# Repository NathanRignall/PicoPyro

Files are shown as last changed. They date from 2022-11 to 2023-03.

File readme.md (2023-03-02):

# Pico Pyro v1.0.1
DMX controlled dual pyrotechnic channels.

## Hardware Overview
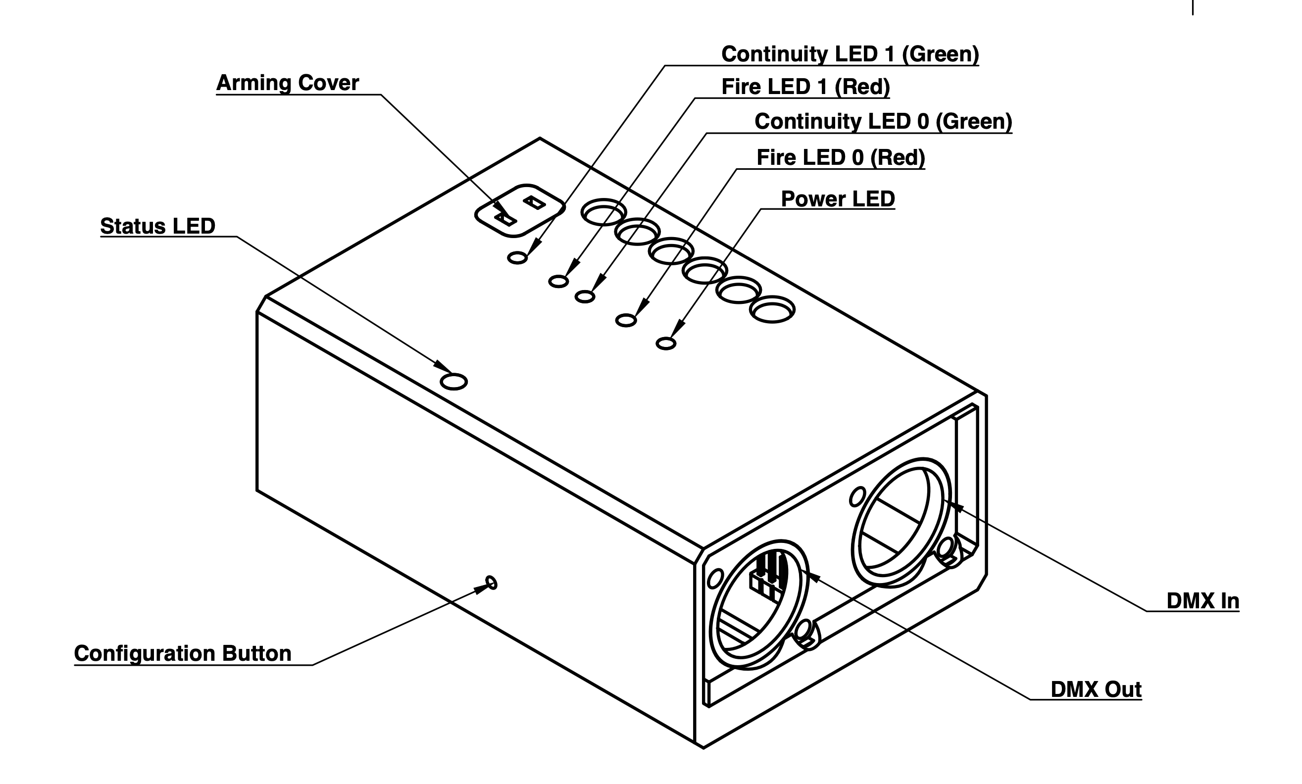
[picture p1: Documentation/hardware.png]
Hardware Diagram

 - Status LED - (WHITE, GREEN, RED, BLUE, PURPLE)
 - Continuity LED - (GREEN)
 - Fire LED - (RED)
 - Configuration Button
 - Arming Cover
 - DMX In/Out

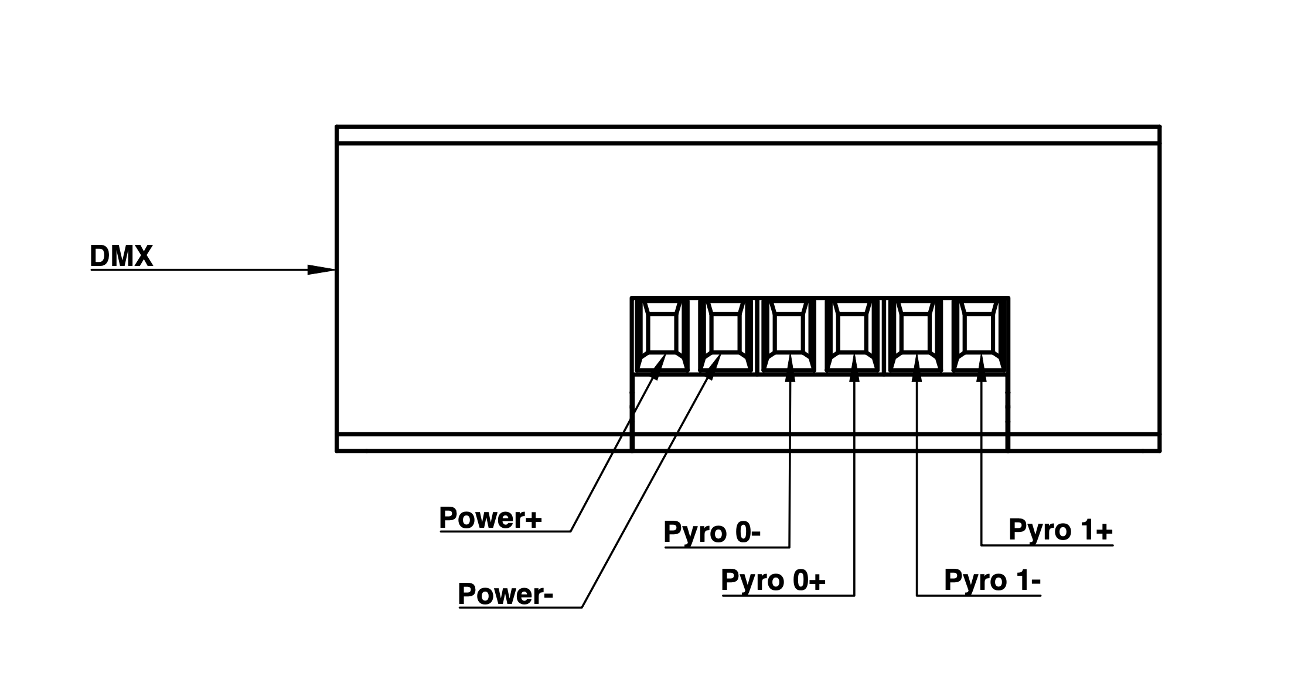
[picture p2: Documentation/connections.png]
Connections Diagram

 - Power+ (3v-50v)
 - Power-
 - Pyro 0/1-
 - Pyro 0/1+

## Modes
The Pico Pyro can be in one of three modes, these are indicated by the status LED.

By default the system enters **active** mode when turned on.

To enter **setup** mode the configuration button must be pressed while being turned on. Setup mode cannot be entered after booting.

If the system detects an invalid configuration during boot the system will enter **failed** mode. To resolved the system must be turned off and back on into setup mode.

### Active
 - Status LED is solid **GREEN** when DMX is detected, **RED** when no DMX signal is detected.
 - Continuity LEDs are **GREEN** when the voltage threshold is met across the pyrotechnic channels. These are used to show if there is a good connection across the hardware connected.
 - Fire LEDs are **RED** when the specified pyrotechnic channel is fired. This occurs when the DMX authorization and fire values are met for that channel.

### Setup
 - Status LED **BLUE**.
 - Continuity LEDs are **GREEN** when the voltage threshold is met across the pyrotechnic channels. These are used to show if there is a good connection across the hardware connected.
 - Fire LEDs and hence pyrotechnic channels off and ***cannot activate***.

### Failed
 - Status LED **PURPLE**.
 - Continuity LEDs off and cannot activate.
 - Fire LEDs and hence pyrotechnic channels off and ***cannot activate***.

## DMX Table

| Channel | Description |
| --- | --- |
| 1 | Pyrotechnic Channel 0 Authorization |
| 2 | Pyrotechnic Channel 1 Authorization |
| 3 | Pyrotechnic Channel 0 Fire |
| 4 | Pyrotechnic Channel 1 Fire |

The DMX values to activate the different channels are specified in the configuration tool.

## Setup
Once entering setup mode the system can be configured using the built-in website. This is accessed by connecting to the WiFi network that is broadcast and navigating to the IP address in the chosen browser.

**SSID** - PicoPyro  
**Password** - itsathing  
**URL** - http://10.66.0.1

The user should be presented with the following...
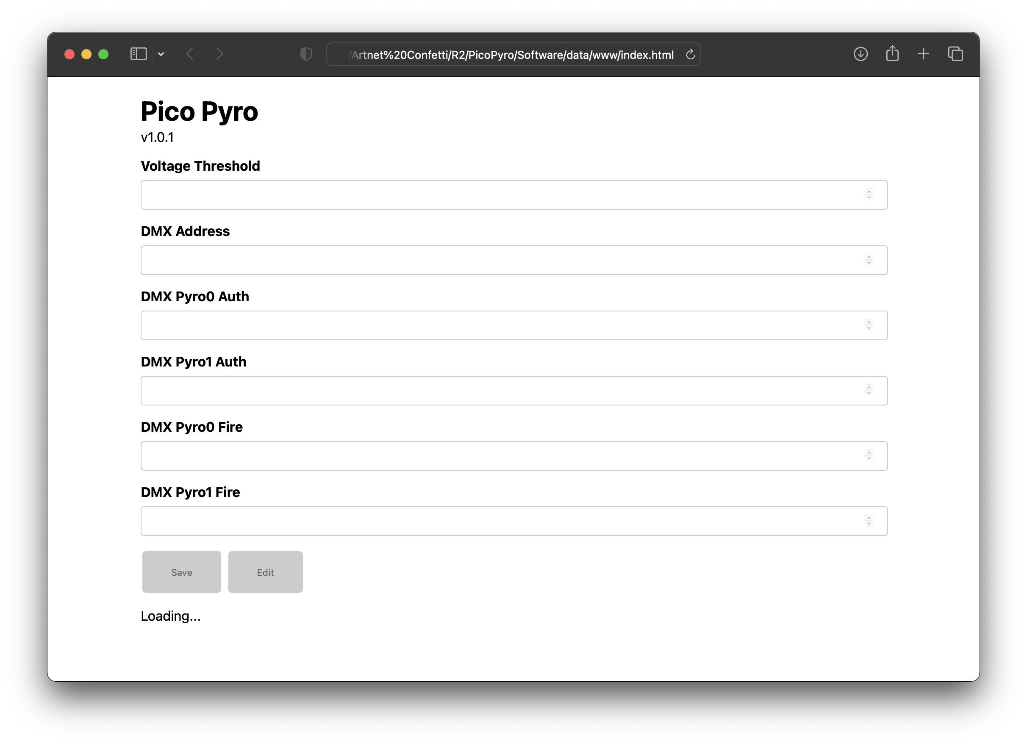
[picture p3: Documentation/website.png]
Website


 - Voltage threshold - (0-1023) - Value used to activate the continuity LEDs. This value is dependant on the supplied voltage. When supplied with around 12v an advised threshold value is 100.
 - DMX Address - (1-251) - Base address for all DMX channels.
 - DMX Pyro0 Auth - (0-255) - Value required to activate channel
 - DMX Pyro1 Auth - (0-255) - Value required to activate channel
 - DMX Pyro0 Fire - (0-255) - Value required to activate channel
 - DMX Pyro1 Fire - (0-255) - Value required to activate channel

## Usage Tips
Ensure all connections are attached.

Arming cover can be removed for rehearsals to test the behaviour of the system without activating pyrotechnic channels.  
When the arming cover is removed the channels are electrically disconnected and cannot fire. The continuity LEDs will temporarily stop working. Fire LEDs will work as expected but won't fire the pyrotechnic channels.  
The recommended method of removing the arming cover is by placing a cable tie through the loop and pulling backwards.

Do not set the activation value to 255, this will increase the chance of accidental activation.  
Instead use a selection of unique, different values.

The easiest way to integrate this system into lighting software is by patching 4 dimmer channels.

## Electronics
Voltage dividers are used for the continuity detection.  
Low voltage dropout is in the voltage regulator.

## Troubleshooting
 - The status LED should be constant **GREEN** when in normal operation.
   - Flickering to **RED** DMX connection is unstable
   - Flickering off supplied voltage is too low (especially during firing)
 - When not activating as expected this could be because the Grand Master is lowering the values slightly.
   - To combat this happening set the 'cue' to ignore the Grand Master

## Legal
We accept no responsibility for the consequences of activating a pyrotechnic.

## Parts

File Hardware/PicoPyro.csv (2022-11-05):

Source: | /Users/nathanrignall/Documents/Development/Projects/Artnet Confetti/R2/PicoPyro/Hardware/PicoPyro.kicad_sch
Date: | Friday, 04 November 2022 at 15:47:25
Tool: | Eeschema (6.0.8-1)-1
Generator: | /Applications/KiCad/KiCad.app/Contents/SharedSupport/plugins/bom_csv_grouped_by_value.py
Component Count: | 46
Individual Components:
Item | Qty | Reference(s) | Value | LibPart | Footprint | Datasheet | Description | Height | MANUFACTURER | MAXIMUM_PACKAGE_HEIGHT | Manufacturer_Name | Manufacturer_Part_Number | Mouser Part Number | Mouser Price/Stock | PARTREV | PN | SNAPEDA_PN | STANDARD
 |  | C101 | 100n | Device:C | Capacitor_SMD:C_0402_1005Metric | ~ |  |  |  |  |  |  |  |  |  | LMK105B7104KVHF
 |  | C102 | 100n | Device:C | Capacitor_SMD:C_0402_1005Metric | ~ |  |  |  |  |  |  |  |  |  | LMK105B7104KVHF
 |  | C301 | 100n | Device:C | Capacitor_SMD:C_0402_1005Metric | ~ |  |  |  |  |  |  |  |  |  | LMK105B7104KVHF
 |  | C501 | 10u | Device:C | Capacitor_SMD:C_0805_2012Metric_Pad1.18x1.45mm_HandSolder | ~
 |  | C502 | 10u | Device:C | Capacitor_SMD:C_0805_2012Metric_Pad1.18x1.45mm_HandSolder | ~
 |  | D201 | LED | Device:LED | LED_SMD:LED_0603_1608Metric | ~
 |  | D211 | LED | Device:LED | LED_SMD:LED_0603_1608Metric | ~
 |  | D301 | WS2812B | LED:WS2812B | LED_SMD:LED_WS2812B_PLCC4_5.0x5.0mm_P3.2mm | https://cdn-shop.adafruit.com/datasheets/WS2812B.pdf
 |  | D401 | LED | Device:LED | LED_SMD:LED_0603_1608Metric | ~
 |  | D411 | LED | Device:LED | LED_SMD:LED_0603_1608Metric | ~
 |  | D601 | LED | Device:LED | LED_SMD:LED_0603_1608Metric | ~
 |  | F201 | 0679H9100-05 | 0679H9100-05:0679H9100-05 | FUSC6125X279N | https://www.belfuse.com/resources/datasheets/circuitprotection/ds-cp-0679h-series.pdf | Surface Mount Fuses 10A 350 VAC 72 VCD | 2.79 |  |  | Stewart Connector | 0679H9100-05 | 530-0679H9100-05 | https://www.mouser.co.uk/ProductDetail/Bel-Fuse/0679H9100-05?qs=acBVhj9v9XU5kfUTxwyepA%3D%3D
 |  | F211 | 0679H9100-05 | 0679H9100-05:0679H9100-05 | FUSC6125X279N | https://www.belfuse.com/resources/datasheets/circuitprotection/ds-cp-0679h-series.pdf | Surface Mount Fuses 10A 350 VAC 72 VCD | 2.79 |  |  | Stewart Connector | 0679H9100-05 | 530-0679H9100-05 | https://www.mouser.co.uk/ProductDetail/Bel-Fuse/0679H9100-05?qs=acBVhj9v9XU5kfUTxwyepA%3D%3D
 |  | J001 | Conn_01x06 | Connector_Generic:Conn_01x06 | Connector_PinSocket_2.54mm:PinSocket_1x06_P2.54mm_Vertical | ~
 |  | J101 | XLR3 | Connector:XLR3 | Connector_Audio:Jack_XLR_Neutrik_NC3FAAH_Horizontal | ~
 |  | J102 | XLR3 | Connector:XLR3 | Connector_Audio:Jack_XLR_Neutrik_NC3MAAH_Horizontal | ~
 |  | J103 | Conn_01x03 | Connector_Generic:Conn_01x03 | Connector_PinHeader_2.54mm:PinHeader_1x03_P2.54mm_Vertical | ~
 |  | J201 | TB005-762-02BE | TB005-762-02BE:TB005-762-02BE | TB00576202BE | https://componentsearchengine.com/Datasheets/1/TB005-762-02BE.pdf | Fixed Terminal Blocks screw type, 7.62 , horizontal, 2 poles, CUI Blue, slotted screw, PCB mount | 21.7 |  |  | CUI Inc. | TB005-762-02BE | 490-TB005-762-02BE | https://www.mouser.co.uk/ProductDetail/CUI-Devices/TB005-762-02BE?qs=vLWxofP3U2zXv1H2wuShow%3D%3D
 |  | J202 | TB005-762-02BE | TB005-762-02BE:TB005-762-02BE | TB00576202BE | https://componentsearchengine.com/Datasheets/1/TB005-762-02BE.pdf | Fixed Terminal Blocks screw type, 7.62 , horizontal, 2 poles, CUI Blue, slotted screw, PCB mount | 21.7 |  |  | CUI Inc. | TB005-762-02BE | 490-TB005-762-02BE | https://www.mouser.co.uk/ProductDetail/CUI-Devices/TB005-762-02BE?qs=vLWxofP3U2zXv1H2wuShow%3D%3D
 |  | J501 | TB005-762-02BE | TB005-762-02BE:TB005-762-02BE | TB00576202BE | https://componentsearchengine.com/Datasheets/1/TB005-762-02BE.pdf | Fixed Terminal Blocks screw type, 7.62 , horizontal, 2 poles, CUI Blue, slotted screw, PCB mount | 21.7 |  |  | CUI Inc. | TB005-762-02BE | 490-TB005-762-02BE | https://www.mouser.co.uk/ProductDetail/CUI-Devices/TB005-762-02BE?qs=vLWxofP3U2zXv1H2wuShow%3D%3D
 |  | J502 | Conn_01x02 | Connector_Generic:Conn_01x02 | Connector_AMASS:AMASS_XT30U-F_1x02_P5.0mm_Vertical | ~
 |  | J503 | Conn_01x02 | Connector_Generic:Conn_01x02 | Connector_PinHeader_2.54mm:PinHeader_1x02_P2.54mm_Vertical | ~
 |  | PS101 | MEE1S0503SC | Converter_DCDC:MEE1S0503SC | Converter_DCDC:Converter_DCDC_Murata_MEE1SxxxxSC_THT | https://power.murata.com/pub/data/power/ncl/kdc_mee1.pdf
 |  | Q201 | TPH9R506PL,LQ | TPH9R506PL_LQ:TPH9R506PL,LQ | TPCA8128L1Q | https://toshiba.semicon-storage.com/ap-en/semiconductor/design-development/package/detail.SOP%20Advance.html | Pb-F POWER MOSFET TRANSISTOR SOP8-ADV PD=81W F=1MHZ | 1 |  |  | Toshiba | TPH9R506PL,LQ | 757-TPH9R506PLLQ | https://www.mouser.co.uk/ProductDetail/Toshiba/TPH9R506PLLQ?qs=h6V4JsTaLXep8RPXchTWuA%3D%3D
 |  | Q211 | TPH9R506PL,LQ | TPH9R506PL_LQ:TPH9R506PL,LQ | TPCA8128L1Q | https://toshiba.semicon-storage.com/ap-en/semiconductor/design-development/package/detail.SOP%20Advance.html | Pb-F POWER MOSFET TRANSISTOR SOP8-ADV PD=81W F=1MHZ | 1 |  |  | Toshiba | TPH9R506PL,LQ | 757-TPH9R506PLLQ | https://www.mouser.co.uk/ProductDetail/Toshiba/TPH9R506PLLQ?qs=h6V4JsTaLXep8RPXchTWuA%3D%3D
 |  | Q501 | DMP2120U-7 | DMP2120U-7:DMP2120U-7 | SOT96P240X110-3N | https://www.diodes.com/assets/Datasheets/DMP2120U.pdf | DMP2120U-7 P-Channel MOSFET, 3 (State) A, 3.8 (Steady) A, 20 V, 3-Pin SOT-23 Diodes Inc | 1.1 |  |  | Diodes Inc. | DMP2120U-7 | 621-DMP2120U-7 | https://www.mouser.co.uk/ProductDetail/Diodes-Incorporated/DMP2120U-7?qs=rrS6PyfT74danH7MTikTvQ%3D%3D
 |  | R101 | 2k | Device:R | Resistor_SMD:R_0402_1005Metric | ~ |  |  |  |  |  |  |  |  |  | RC0402FR-071KP‎
 |  | R102 | 120 | Device:R | Resistor_SMD:R_0402_1005Metric | ~ |  |  |  |  |  |  |  |  |  | RC0402FR-071KP‎
 |  | R103 | 680 | Device:R | Resistor_SMD:R_0402_1005Metric | ~ |  |  |  |  |  |  |  |  |  | RC0402FR-071KP‎
 |  | R104 | 680 | Device:R | Resistor_SMD:R_0402_1005Metric | ~ |  |  |  |  |  |  |  |  |  | RC0402FR-071KP‎
 |  | R201 | 10k | Device:R | Resistor_SMD:R_0402_1005Metric | ~ |  |  |  |  |  |  |  |  |  | RC0402FR-0710KL‎
 |  | R202 | 500 | Device:R | Resistor_SMD:R_0402_1005Metric | ~ |  |  |  |  |  |  |  |  |  | RC0402FR-071KP‎
 |  | R203 | 150k | Device:R | Resistor_SMD:R_0402_1005Metric | ~ |  |  |  |  |  |  |  |  |  | RC0402FR-07150KL
 |  | R204 | 10k | Device:R | Resistor_SMD:R_0402_1005Metric | ~ |  |  |  |  |  |  |  |  |  | RC0402FR-0730KL
 |  | R211 | 10k | Device:R | Resistor_SMD:R_0402_1005Metric | ~ |  |  |  |  |  |  |  |  |  | RC0402FR-0710KL‎
 |  | R212 | 500 | Device:R | Resistor_SMD:R_0402_1005Metric | ~ |  |  |  |  |  |  |  |  |  | RC0402FR-071KP‎
 |  | R213 | 150k | Device:R | Resistor_SMD:R_0402_1005Metric | ~ |  |  |  |  |  |  |  |  |  | RC0402FR-07150KL
 |  | R214 | 10k | Device:R | Resistor_SMD:R_0402_1005Metric | ~ |  |  |  |  |  |  |  |  |  | RC0402FR-0730KL
 |  | R401 | 500 | Device:R | Resistor_SMD:R_0402_1005Metric | ~ |  |  |  |  |  |  |  |  |  | RC0402FR-071KP‎
 |  | R411 | 500 | Device:R | Resistor_SMD:R_0402_1005Metric | ~ |  |  |  |  |  |  |  |  |  | RC0402FR-071KP‎
 |  | R601 | 1k | Device:R | Resistor_SMD:R_0402_1005Metric | ~ |  |  |  |  |  |  |  |  |  | RC0402FR-071KP‎
 |  | R701 | 10k | Device:R | Resistor_SMD:R_0402_1005Metric | ~ |  |  |  |  |  |  |  |  |  | RC0402FR-071KP‎
 |  | S701 | TS11-674-43-BK-100-RA-D | TS11-674-43-BK-100-RA-D:TS11-674-43-BK-100-RA-D | TS1167443BK100RAD |  | contact resistance applying load of 2 times operating force at 5 Vdc, 10 mA | 6.2 |  |  | CUI Inc. | TS11-674-43-BK-100-RA-D | 179-TS1167443100RAD | https://www.mouser.co.uk/ProductDetail/CUI-Devices/TS11-674-43-BK-100-RA-D?qs=t7xnP681wgXdE8xMO2SjSQ%3D%3D
 |  | U001 | Pico | MCU_RaspberryPi_and_Boards:Pico | MCU_RaspberryPi_and_Boards:RPi_Pico_SMD_TH
 |  | U101 | ADM2483xRW | Interface_UART:ADM2483xRW | Package_SO:SOIC-16W_7.5x10.3mm_P1.27mm | https://www.analog.com/media/en/technical-documentation/data-sheets/adm2483.pdf
 |  | U501 | TQL850CSV50 | TQL850CSV50:TQL850CSV50 | SOIC127P600X170-9N |  |  |  | Taiwan Semiconductor | 1.7 mm |  |  |  |  | A2206 |  | TQL850CSV50 | IPC 7351B
Collated Components:
Item | Qty | Reference(s) | Value | LibPart | Footprint | Datasheet | Description | Height | MANUFACTURER | MAXIMUM_PACKAGE_HEIGHT | Manufacturer_Name | Manufacturer_Part_Number | Mouser Part Number | Mouser Price/Stock | PARTREV | PN | SNAPEDA_PN | STANDARD
1 | 3 | C101, C102, C301 | 100n | Device:C | Capacitor_SMD:C_0402_1005Metric | ~ |  |  |  |  |  |  |  |  |  | LMK105B7104KVHF
2 | 2 | C501, C502 | 10u | Device:C | Capacitor_SMD:C_0805_2012Metric_Pad1.18x1.45mm_HandSolder | ~
3 | 5 | D201, D211, D401, D411, D601 | LED | Device:LED | LED_SMD:LED_0603_1608Metric | ~
4 | 1 | D301 | WS2812B | LED:WS2812B | LED_SMD:LED_WS2812B_PLCC4_5.0x5.0mm_P3.2mm | https://cdn-shop.adafruit.com/datasheets/WS2812B.pdf
5 | 2 | F201, F211 | 0679H9100-05 | 0679H9100-05:0679H9100-05 | FUSC6125X279N | https://www.belfuse.com/resources/datasheets/circuitprotection/ds-cp-0679h-series.pdf | Surface Mount Fuses 10A 350 VAC 72 VCD | 2.79 |  |  | Stewart Connector | 0679H9100-05 | 530-0679H9100-05 | https://www.mouser.co.uk/ProductDetail/Bel-Fuse/0679H9100-05?qs=acBVhj9v9XU5kfUTxwyepA%3D%3D
6 | 1 | J001 | Conn_01x06 | Connector_Generic:Conn_01x06 | Connector_PinSocket_2.54mm:PinSocket_1x06_P2.54mm_Vertical | ~
7 | 1 | J101 | XLR3 | Connector:XLR3 | Connector_Audio:Jack_XLR_Neutrik_NC3FAAH_Horizontal | ~
8 | 1 | J102 | XLR3 | Connector:XLR3 | Connector_Audio:Jack_XLR_Neutrik_NC3MAAH_Horizontal | ~
9 | 1 | J103 | Conn_01x03 | Connector_Generic:Conn_01x03 | Connector_PinHeader_2.54mm:PinHeader_1x03_P2.54mm_Vertical | ~
10 | 3 | J201, J202, J501 | TB005-762-02BE | TB005-762-02BE:TB005-762-02BE | TB00576202BE | https://componentsearchengine.com/Datasheets/1/TB005-762-02BE.pdf | Fixed Terminal Blocks screw type, 7.62 , horizontal, 2 poles, CUI Blue, slotted screw, PCB mount | 21.7 |  |  | CUI Inc. | TB005-762-02BE | 490-TB005-762-02BE | https://www.mouser.co.uk/ProductDetail/CUI-Devices/TB005-762-02BE?qs=vLWxofP3U2zXv1H2wuShow%3D%3D
11 | 1 | J502 | Conn_01x02 | Connector_Generic:Conn_01x02 | Connector_AMASS:AMASS_XT30U-F_1x02_P5.0mm_Vertical | ~
12 | 1 | J503 | Conn_01x02 | Connector_Generic:Conn_01x02 | Connector_PinHeader_2.54mm:PinHeader_1x02_P2.54mm_Vertical | ~
13 | 1 | PS101 | MEE1S0503SC | Converter_DCDC:MEE1S0503SC | Converter_DCDC:Converter_DCDC_Murata_MEE1SxxxxSC_THT | https://power.murata.com/pub/data/power/ncl/kdc_mee1.pdf
14 | 2 | Q201, Q211 | TPH9R506PL,LQ | TPH9R506PL_LQ:TPH9R506PL,LQ | TPCA8128L1Q | https://toshiba.semicon-storage.com/ap-en/semiconductor/design-development/package/detail.SOP%20Advance.html | Pb-F POWER MOSFET TRANSISTOR SOP8-ADV PD=81W F=1MHZ | 1 |  |  | Toshiba | TPH9R506PL,LQ | 757-TPH9R506PLLQ | https://www.mouser.co.uk/ProductDetail/Toshiba/TPH9R506PLLQ?qs=h6V4JsTaLXep8RPXchTWuA%3D%3D
15 | 1 | Q501 | DMP2120U-7 | DMP2120U-7:DMP2120U-7 | SOT96P240X110-3N | https://www.diodes.com/assets/Datasheets/DMP2120U.pdf | DMP2120U-7 P-Channel MOSFET, 3 (State) A, 3.8 (Steady) A, 20 V, 3-Pin SOT-23 Diodes Inc | 1.1 |  |  | Diodes Inc. | DMP2120U-7 | 621-DMP2120U-7 | https://www.mouser.co.uk/ProductDetail/Diodes-Incorporated/DMP2120U-7?qs=rrS6PyfT74danH7MTikTvQ%3D%3D
16 | 1 | R101 | 2k | Device:R | Resistor_SMD:R_0402_1005Metric | ~ |  |  |  |  |  |  |  |  |  | RC0402FR-071KP‎
17 | 1 | R102 | 120 | Device:R | Resistor_SMD:R_0402_1005Metric | ~ |  |  |  |  |  |  |  |  |  | RC0402FR-071KP‎
18 | 2 | R103, R104 | 680 | Device:R | Resistor_SMD:R_0402_1005Metric | ~ |  |  |  |  |  |  |  |  |  | RC0402FR-071KP‎
19 | 5 | R201, R204, R211, R214, R701 | 10k | Device:R | Resistor_SMD:R_0402_1005Metric | ~ |  |  |  |  |  |  |  |  |  | RC0402FR-0710KL‎
20 | 4 | R202, R212, R401, R411 | 500 | Device:R | Resistor_SMD:R_0402_1005Metric | ~ |  |  |  |  |  |  |  |  |  | RC0402FR-071KP‎
21 | 2 | R203, R213 | 150k | Device:R | Resistor_SMD:R_0402_1005Metric | ~ |  |  |  |  |  |  |  |  |  | RC0402FR-07150KL
22 | 1 | R601 | 1k | Device:R | Resistor_SMD:R_0402_1005Metric | ~ |  |  |  |  |  |  |  |  |  | RC0402FR-071KP‎
23 | 1 | S701 | TS11-674-43-BK-100-RA-D | TS11-674-43-BK-100-RA-D:TS11-674-43-BK-100-RA-D | TS1167443BK100RAD |  | contact resistance applying load of 2 times operating force at 5 Vdc, 10 mA | 6.2 |  |  | CUI Inc. | TS11-674-43-BK-100-RA-D | 179-TS1167443100RAD | https://www.mouser.co.uk/ProductDetail/CUI-Devices/TS11-674-43-BK-100-RA-D?qs=t7xnP681wgXdE8xMO2SjSQ%3D%3D
24 | 1 | U001 | Pico | MCU_RaspberryPi_and_Boards:Pico | MCU_RaspberryPi_and_Boards:RPi_Pico_SMD_TH
25 | 1 | U101 | ADM2483xRW | Interface_UART:ADM2483xRW | Package_SO:SOIC-16W_7.5x10.3mm_P1.27mm | https://www.analog.com/media/en/technical-documentation/data-sheets/adm2483.pdf
26 | 1 | U501 | TQL850CSV50 | TQL850CSV50:TQL850CSV50 | SOIC127P600X170-9N |  |  |  | Taiwan Semiconductor | 1.7 mm |  |  |  |  | A2206 |  | TQL850CSV50 | IPC 7351B

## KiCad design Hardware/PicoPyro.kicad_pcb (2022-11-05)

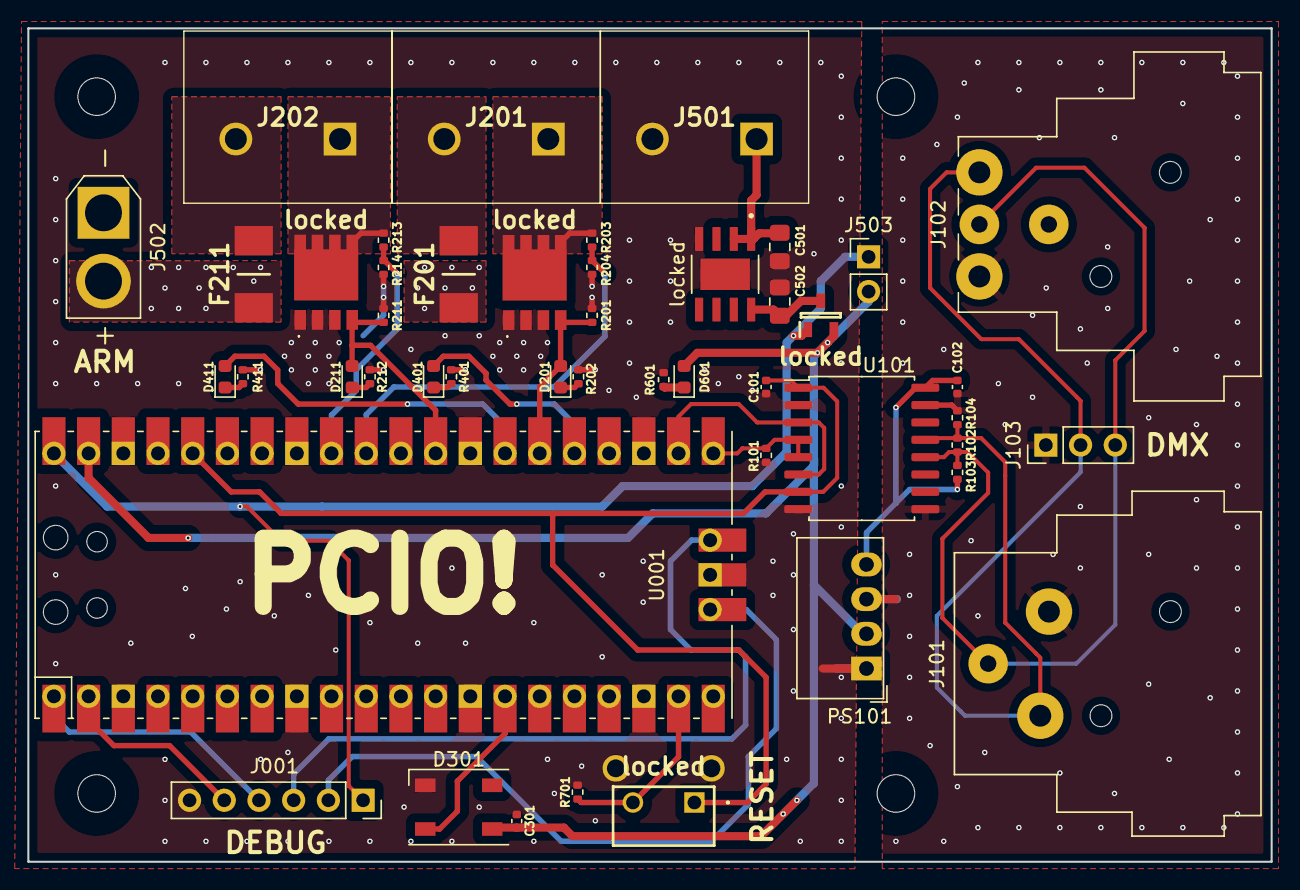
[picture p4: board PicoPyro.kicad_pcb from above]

Board: 2 copper layers, 91.0 x 61.0 mm, 46 parts (0 on the bottom side), 34 nets.

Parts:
C101, C102, C301: 100n; C_0402_1005Metric
C501, C502: 10u; C_0805_2012Metric_Pad1.18x1.45mm_HandSolder
D201, D211, D401, D411, D601: LED; LED_0603_1608Metric
D301: WS2812B; LED_WS2812B_PLCC4_5.0x5.0mm_P3.2mm
F201, F211: 0679H9100-05; FUSC6125X279N
J001: Conn_01x06; PinSocket_1x06_P2.54mm_Vertical
J101: XLR3; Jack_XLR_Neutrik_NC3FAAH_Horizontal
J102: XLR3; Jack_XLR_Neutrik_NC3MAAH_Horizontal
J103: Conn_01x03; PinHeader_1x03_P2.54mm_Vertical
J201, J202, J501: TB005-762-02BE; TB00576202BE
J502: Conn_01x02; AMASS_XT30U-F_1x02_P5.0mm_Vertical
J503: Conn_01x02; PinHeader_1x02_P2.54mm_Vertical
PS101: MEE1S0503SC; Converter_DCDC_Murata_MEE1SxxxxSC_THT
R101: 2k; R_0402_1005Metric
R102: 120; R_0402_1005Metric
R103, R104: 680; R_0402_1005Metric
R201, R204, R211, R214, R701: 10k; R_0402_1005Metric
R202, R212, R401, R411: 500; R_0402_1005Metric
R203, R213: 150k; R_0402_1005Metric
R601: 1k; R_0402_1005Metric
U001: Pico; RPi_Pico_SMD_TH
U101: ADM2483xRW; SOIC-16W_7.5x10.3mm_P1.27mm
locked: TS11-674-43-BK-100-RA-D; TS1167443BK100RAD
locked#2: TQL850CSV50; SOIC127P600X170-9N
locked#3: DMP2120U-7; SOT96P240X110-3N
locked#4, locked#5: TPH9R506PL,LQ; TPCA8128L1Q

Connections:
+3V3: C101.1, U001.36 (3V3), U101.1 (VDD1), U101.7 (PV), locked.1 (COM)
+5V: C301.1, D301.1 (VDD), D601.2 (A), J503.2, PS101.2 (+Vin), U001.39 (VSYS), locked#3.2
/5V_DMX: C102.1, PS101.4 (+Vout), R103.1, U101.16 (VDD2)
/ARM: F201.2, F211.2, J502.2
/BUTTON_MODE: R701.2, U001.19 (GPIO14), locked.2 (NO)
/DEBUG_CLK: J001.2, U001.41 (SWCLK)
/DEBUG_DIO: J001.3, U001.43 (SWDIO)
/DMX_IO: U001.22 (GPIO17), U101.3 (RxD), U101.6 (TxD)
/DMX_RDM: R101.1, U001.21 (GPIO16), U101.4 (~RE), U101.5 (DE)
/GND_DMX: C102.2, J101.1, J102.1, J103.1, PS101.3 (-Vout), R104.2, U101.9 (GND2), U101.15 (GND2)
/LED_STATUS: D301.4 (DIN), U001.14 (GPIO10)
/PYRO0_FIRE: D201.2 (A), R201.2, U001.26 (GPIO20), locked#4.4 (G)
/PYRO0_LED: D401.2 (A), U001.25 (GPIO19)
/PYRO0_MEASURE: R203.2, R204.2, U001.31 (GPIO26_ADC0)
/PYRO1_FIRE: D211.2 (A), R211.2, U001.29 (GPIO22), locked#5.4 (G)
/PYRO1_LED: D411.2 (A), U001.27 (GPIO21)
/PYRO1_MEASURE: R213.2, R214.2, U001.32 (GPIO27_ADC1)
/UART0_RX: J001.5, U001.2 (GPIO1)
/UART0_TX: J001.4, U001.1 (GPIO0)
GND: C101.2, C301.2, C501.1, C502.2, D301.3 (VSS), J001.6, J501.2, PS101.1 (-Vin), R101.2, R201.1, R202.2, R204.1, R211.1, R212.2, R214.1, R401.2, R411.2, R601.2, R701.1, U001.3 (GND), U001.8 (GND), U001.13 (GND), U001.18 (GND), U001.23 (GND), U001.28 (GND), U001.33 (AGND), U001.38 (GND), U001.42 (GND), U101.2 (GND1), U101.8 (GND1), locked.3 (GND_1), locked.4 (GND_2), locked#2.4 (GND), locked#2.9 (EXP), locked#4.1 (S_1), locked#4.2 (S_2), locked#4.3 (S_3), locked#5.1 (S_1), locked#5.2 (S_2), locked#5.3 (S_3)
unnamed: C501.2, J501.1, J502.1, locked#2.1 (IN), locked#2.2 (EN)
unnamed: D201.1 (K), R202.1
unnamed: D211.1 (K), R212.1
unnamed: D401.1 (K), R401.1
unnamed: D411.1 (K), R411.1
unnamed: D601.1 (K), R601.1
unnamed: J101.2, J102.2, J103.2, R102.2, R104.1, U101.13 (B)
unnamed: J101.3, J102.3, J103.3, R102.1, R103.2, U101.12 (A)
unnamed: J201.1, R203.1, locked#4.5 (D_1), locked#4.6 (D_2), locked#4.7 (D_3), locked#4.8 (D_4), locked#4.9 (D_5)
unnamed: F201.1, J201.2
unnamed: J202.1, R213.1, locked#5.5 (D_1), locked#5.6 (D_2), locked#5.7 (D_3), locked#5.8 (D_4), locked#5.9 (D_5)
unnamed: F211.1, J202.2
unnamed: C502.1, locked#2.8 (OUT), locked#3.3
VBUS: J001.1, J503.1, U001.40 (VBUS), locked#3.1

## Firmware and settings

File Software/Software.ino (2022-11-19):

/* Copyright (C) 2022 Nathan Rignall
 * Unauthorized copying of this file, via any medium is strictly prohibited
 * Proprietary and confidential
 * Last modified 2022-11
 */

#include "DmxInput.h"
#include "LittleFS.h"
#include "ArduinoJson.h"

#include <pico/cyw43_arch.h>
#include <AsyncFSEditor_RP2040W.h>
#include <AsyncWebServer_RP2040W.h>

#include <DNSServer.h>
#include <Adafruit_NeoPixel.h>

#include "software.h"

// ------ Shared variables ------

enum State system_state = BOOT;
struct Config system_config = {100, 1, 255, 255, 255, 255};

bool setup_done = false;
bool setup_config_done = false;
bool setup_inputs_done = false;
bool setup_outputs_done = false;
bool setup_pyro_done = false;
bool setup_dmx_done = false;
bool setup_settings_done = false;

// ------ Input sepecific variables ------

const int reset_button_pin = 14;

const int pyro0_measure_pin = 26;
const int pyro1_measure_pin = 27;

// ------ Output sepecific variables ------

const int led_pin = 25;

const int pyro0_led_pin = 19;
const int pyro1_led_pin = 21;

const int status_led_pin = 10;
int status_led_format = NEO_GRB + NEO_KHZ800;
Adafruit_NeoPixel *status_led_pixels;

// ------ Pyro sepecific variables ------

const int pyro0_fire_pin = 20;
const int pyro1_fire_pin = 22;

// ------ DMX specific variables ------

const int dmx_rdm_pin = 16;
const int dmx_io_pin = 17;

const int dmx_start_channel = 1;
const int dmx_num_channels = 255;

DmxInput dmxInput;
volatile uint8_t dmx_buffer[DMXINPUT_BUFFER_SIZE(dmx_start_channel, dmx_num_channels)];

// ------ Settings specific variables ------

const byte DNS_PORT = 53;

const char *ssid = "PicoPyro";
const char *password = "itsathing";

IPAddress apIP(10, 66, 0, 1);

AsyncWebServer server(80);
AsyncWebSocket ws("/ws");
DNSServer dnsServer;

// ------ Setup functions ------

void setup_config()
{

  // Check if already setup
  if (setup_config_done)
  {
    return;
  }

  // setup LittleFS
  if (!LittleFS.begin())
  {
    Serial.println("Failed to mount LittleFS \n");
    system_state = FAILED;
    return;
  }

  // load config
  if (!load_config(&system_config))
  {
    Serial.println("Failed to load config \n");
    system_state = FAILED;
    return;
  }

  Serial.println("Config setup \n");

  // Set done to true
  setup_config_done = true;
}

void setup_inputs()
{

  // Check if already setup
  if (setup_inputs_done)
  {
    return;
  }

  pinMode(reset_button_pin, INPUT);
  Serial.println("Reset button setup \n");

  // Set done to true
  setup_inputs_done = true;
}

void setup_outputs()
{

  // Check if already setup
  if (setup_outputs_done)
  {
    return;
  }

  pinMode(led_pin, OUTPUT);
  digitalWrite(led_pin, 0);
  Serial.println("Inbuilt led setup \n");

  pinMode(pyro0_led_pin, OUTPUT);
  digitalWrite(pyro0_led_pin, 0);
  Serial.println("Pyro0 led setup \n");

  pinMode(pyro1_led_pin, OUTPUT);
  digitalWrite(pyro1_led_pin, 0);
  Serial.println("Pyro1 led setup \n");

  // setup the status led and set it to white
  status_led_pixels = new Adafruit_NeoPixel(1, status_led_pin, status_led_format);
  status_led_pixels->begin();
  status_led_pixels->setBrightness(50);
  status_led_pixels->clear();
  status_led_pixels->setPixelColor(0, status_led_pixels->Color(255, 255, 255));
  status_led_pixels->show();
  Serial.println("Setatus led setup \n");

  // Set done to true
  setup_outputs_done = true;
}

void setup_pyro()
{

  // Check if already setup
  if (setup_pyro_done)
  {
    return;
  }

  pinMode(pyro0_fire_pin, OUTPUT);
  digitalWrite(pyro0_fire_pin, 0);
  Serial.println("Pyro0 fire setup \n");

  pinMode(pyro1_fire_pin, OUTPUT);
  digitalWrite(pyro1_fire_pin, 0);
  Serial.println("Pyro1 fire setup \n");

  // Set done to true
  setup_pyro_done = true;
}

void setup_dmx()
{
  // Check if already setup
  if (setup_settings_done)
  {
    return;
  }

  // Setup RDM
  pinMode(pyro1_fire_pin, OUTPUT);
  digitalWrite(pyro1_fire_pin, 0);
  Serial.println("DMX RDM setup \n");

  // Setup DMX
  dmxInput.begin(dmx_io_pin, dmx_start_channel, dmx_num_channels);
  dmxInput.read_async(dmx_buffer);
  Serial.println("DMX input started \n");

  // set done to true
  setup_dmx_done = true;
}

void on_ws_event(AsyncWebSocket *server, AsyncWebSocketClient *client, AwsEventType type, void *arg, uint8_t *data, size_t len)
{
  // return json object and string
  StaticJsonDocument<1024> return_doc;
  String output;

  if (type == WS_EVT_CONNECT)
  {
    // debug message
    Serial.printf("ws[Server: %s][ClientID: %u] WSClient connected\n", server->url(), client->id());

    // send the current config
    return_doc["config"]["voltage_threshold"] = system_config.voltage_threshold;
    return_doc["config"]["dmx_address"] = system_config.dmx_address;
    return_doc["config"]["dmx_pyro0_auth"] = system_config.dmx_pyro0_auth;
    return_doc["config"]["dmx_pyro1_auth"] = system_config.dmx_pyro1_auth;
    return_doc["config"]["dmx_pyro0_fire"] = system_config.dmx_pyro0_fire;
    return_doc["config"]["dmx_pyro1_fire"] = system_config.dmx_pyro1_fire;
    return_doc["status"] = "Existing config loaded";
    serializeJson(return_doc, output);
    client->text(output);
  }
  else if (type == WS_EVT_DISCONNECT)
  {
    // debug message
    Serial.printf("ws[Server: %s][ClientID: %u] WSClient disconnected\n", server->url(), client->id());
  }
  else if (type == WS_EVT_ERROR)
  {
    // debug message
    Serial.printf("ws[Server: %s][ClientID: %u] error(%u): %s\n", server->url(), client->id(), *((uint16_t *)arg), (char *)data);
  }
  else if (type == WS_EVT_DATA)
  {
    // data packet
    AwsFrameInfo *info = (AwsFrameInfo *)arg;

    if (info->final && info->index == 0 && info->len == len)
    {
      if (info->opcode == WS_TEXT)
      {
        data[len] = 0;

        // convert data to json
        StaticJsonDocument<1024> input_doc;
        DeserializationError error = deserializeJson(input_doc, data);

        // check if there is an error
        if (error)
        {
          // send json error
          return_doc["status"] = "Could not decode json";
          serializeJson(return_doc, output);
          client->text(output);

          return;
        }

        // check if the message is config
        if (input_doc.containsKey("config"))
        {
          // get the config
          JsonObject config = input_doc["config"];

          // check if the config is valid
          if (check_config(config))
          {

            // save the config
            if (save_config(config))
            {

              // load the config
              if (load_config(&system_config))
              {
                // send the new config
                return_doc["config"]["voltage_threshold"] = system_config.voltage_threshold;
                return_doc["config"]["dmx_address"] = system_config.dmx_address;
                return_doc["config"]["dmx_pyro0_auth"] = system_config.dmx_pyro0_auth;
                return_doc["config"]["dmx_pyro1_auth"] = system_config.dmx_pyro1_auth;
                return_doc["config"]["dmx_pyro0_fire"] = system_config.dmx_pyro0_fire;
                return_doc["config"]["dmx_pyro1_fire"] = system_config.dmx_pyro1_fire;
                return_doc["status"] = "Config saved and loaded";
                serializeJson(return_doc, output);
                client->text(output);
              }
              else
              {
                // send json status
                return_doc["status"] = "Failed to load config";
                serializeJson(return_doc, output);
                client->text(output);
              }
            }
            else
            {
              // send json status
              return_doc["status"] = "Could not save config";
              serializeJson(return_doc, output);
              client->text(output);
            }
          }
          else
          {
            // send json status
            return_doc["status"] = "Invalid config";
            serializeJson(return_doc, output);
            client->text(output);
          }
        }
        else
        {
          // debug message
          Serial.println("Invalid message \n");

          // send json error
          return_doc["status"] = "Invalid message";
          serializeJson(return_doc, output);
          client->text(output);
        }
      }
    }
  }
}

void setup_settings()
{
  // Check if already setup
  if (setup_settings_done)
  {
    return;
  }

  // Setup Wifi
  WiFi.mode(WIFI_AP);
  WiFi.softAPConfig(apIP, apIP, IPAddress(255, 255, 255, 0));
  WiFi.softAP(ssid, password);
  Serial.println("Wifi AP started \n");

  // Setup DNS server
  dnsServer.start(DNS_PORT, "picopyro", apIP);
  dnsServer.start(DNS_PORT, "picopyro", apIP);
  Serial.println("DNS server started \n");

  // Setup the webserver
  ws.onEvent(on_ws_event);
  server.addHandler(&ws);
  server.serveStatic("/", LittleFS, "/www/").setDefaultFile("index.html");
  server.begin();
  Serial.println("Webserver Setup \n");

  // Set done to true
  setup_settings_done = true;
}

void setup()
{
  // setup serial
  Serial.begin(115200);
  Serial.println("Serial started \n");

  // Setup hardware required by all
  setup_config();

  // setup inputs and outputs
  setup_inputs();
  setup_outputs();
  setup_dmx();

  // Set the system state
  if (digitalRead(reset_button_pin))
  {
    system_state = SETTINGS;
  }
  else
  {
    // check if system has failed before active
    if (system_state == FAILED)
    {
      Serial.println("System failed! \n");
      return;
    }
    else
    {
      system_state = ACTIVE;
    }
  }

  // Setup the correct hardware based on run mode
  switch (system_state)
  {
  case SETTINGS:

    setup_settings();
    break;

  case ACTIVE:

    setup_pyro();
    break;
  }

  Serial.println("Setup Complete! \n");
  setup_done = true;

  // print version message
  Serial.println("Nathan Rignall - Pico Pyro - v1.0.1 \n");

  // wait for dmx
  delay(150);
}

// ------ Loop functions ------

void loop_inputs(Inputs *inputs)
{
  inputs->pyro0_measure = analogRead(pyro0_measure_pin);
  inputs->pyro1_measure = analogRead(pyro1_measure_pin);
}

void loop_outputs(Outputs outputs)
{
  digitalWrite(pyro0_led_pin, outputs.pyro0_led);
  digitalWrite(pyro1_led_pin, outputs.pyro1_led);

  status_led_pixels->clear();

  switch (outputs.status_led)
  {

  case LED_ACTIVE:
    status_led_pixels->setPixelColor(0, status_led_pixels->Color(0, 255, 0));
    break;

  case LED_ERROR:
    status_led_pixels->setPixelColor(0, status_led_pixels->Color(255, 0, 0));
    break;

  case LED_SETUP:
    status_led_pixels->setPixelColor(0, status_led_pixels->Color(0, 0, 255));
    break;

  case LED_FAILED:
    status_led_pixels->setPixelColor(0, status_led_pixels->Color(255, 0, 255));
    break;
  }

  status_led_pixels->show();
}

void loop_pyro(Pyro pyro)
{
  digitalWrite(pyro0_fire_pin, pyro.pyro0_fire);
  digitalWrite(pyro1_fire_pin, pyro.pyro1_fire);
}

void loop_dmx(DMX *dmx)
{
  if (millis() > 150 + dmxInput.latest_packet_timestamp())
  {
    dmx->data = false;
  }
  else
  {
    dmx->data = true;
  }
}

void loop_settings()
{
  dnsServer.processNextRequest();
}

void loop()
{
  // main control loop for core0
  // all processing should be done here

  // local vars
  DMX dmx = {0};
  Inputs inputs = {0, 0};
  Outputs outputs = {0, 0, LED_FAILED};
  Pyro pyro = {0, 0};

  // control loop
  switch (system_state)
  {
  case SETTINGS:

    loop_dmx(&dmx);
    loop_inputs(&inputs);

    loop_settings();
    proccess_logic(system_state, dmx, inputs, &outputs, &pyro);

    loop_outputs(outputs);

    break;

  case ACTIVE:

    loop_dmx(&dmx);
    loop_inputs(&inputs);

    proccess_logic(system_state, dmx, inputs, &outputs, &pyro);

    loop_outputs(outputs);
    loop_pyro(pyro);

    break;

  case FAILED:

    proccess_logic(system_state, dmx, inputs, &outputs, &pyro);

    loop_outputs(outputs);

    break;
  }
}

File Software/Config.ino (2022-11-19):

/* Copyright (C) 2022 Nathan Rignall
 * Unauthorized copying of this file, via any medium is strictly prohibited
 * Proprietary and confidential
 * Last modified 2022-11
 */

#include "ArduinoJson.h"
#include "LittleFS.h"

#include "software.h"

// check the provided json document for correct format
bool check_config(StaticJsonDocument<1024> document)
{

  // check all keys are present
  if (!document.containsKey("voltage_threshold"))
  {
    Serial.println("Config is missing voltage_threshold \n");
    return false;
  }

  if (!document.containsKey("dmx_address"))
  {
    Serial.println("Config is missing dmx_address \n");
    return false;
  }

  if (!document.containsKey("dmx_pyro0_auth"))
  {
    Serial.println("Config is missing dmx_pyro0_auth \n");
    return false;
  }

  if (!document.containsKey("dmx_pyro1_auth"))
  {
    Serial.println("Config is missing dmx_pyro1_auth \n");
    return false;
  }

  if (!document.containsKey("dmx_pyro0_fire"))
  {
    Serial.println("Config is missing dmx_pyro0_fire \n");
    return false;
  }

  if (!document.containsKey("dmx_pyro1_fire"))
  {
    Serial.println("Config is missing dmx_pyro1_fire \n");
    return false;
  }

  // save config to temp_config to check if it is valid
  struct Config temp_config;
  temp_config.voltage_threshold = document["voltage_threshold"];
  temp_config.dmx_address = document["dmx_address"];
  temp_config.dmx_pyro0_auth = document["dmx_pyro0_auth"];
  temp_config.dmx_pyro1_auth = document["dmx_pyro1_auth"];
  temp_config.dmx_pyro0_fire = document["dmx_pyro0_fire"];
  temp_config.dmx_pyro1_fire = document["dmx_pyro1_fire"];

  // check config is in bounds
  if (temp_config.voltage_threshold < 0 || temp_config.voltage_threshold > 1023)
  {
    Serial.println("Config voltage_threshold is out of bounds \n");
    return false;
  }

  if (temp_config.dmx_address < 1 || temp_config.dmx_address > 251)
  {
    Serial.println("Config dmx_address is out of bounds \n");
    return false;
  }

  if (temp_config.dmx_pyro0_auth < 0 || temp_config.dmx_pyro0_auth > 255)
  {
    Serial.println("Config dmx_pyro0_auth is out of bounds \n");
    return false;
  }

  if (temp_config.dmx_pyro1_auth < 0 || temp_config.dmx_pyro1_auth > 255)
  {
    Serial.println("Config dmx_pyro1_auth is out of bounds \n");
    return false;
  }

  if (temp_config.dmx_pyro0_fire < 0 || temp_config.dmx_pyro0_fire > 255)
  {
    Serial.println("Config dmx_pyro0_fire is out of bounds \n");
    return false;
  }

  if (temp_config.dmx_pyro1_fire < 0 || temp_config.dmx_pyro1_fire > 255)
  {
    Serial.println("Config dmx_pyro1_fire is out of bounds \n");
    return false;
  }

  Serial.println("Config checked \n");

  return true;
}

// save the provided json document to the config file
bool save_config(StaticJsonDocument<1024> document)
{

  if (!check_config(document))
  {
    Serial.println("Config is invalid \n");
    return false;
  }

  File file = LittleFS.open("/config.json", "w");

  if (!file)
  {
    Serial.println("Could not open config for writing \n");
    return false;
  }

  serializeJson(document, file);
  file.close();

  Serial.println("Config saved \n");

  return true;
}

// load the config file into config struct
bool load_config(Config *config)
{

  File file = LittleFS.open("/config.json", "r");

  if (!file)
  {
    Serial.println("Could not open config for reading \n");
    return false;
  }

  StaticJsonDocument<1024> document;
  DeserializationError error = deserializeJson(document, file);

  file.close();

  if (error)
  {
    Serial.println("Could not parse config \n");
    return false;
  }

  if (!check_config(document))
  {
    Serial.println("Config is invalid \n");
    return false;
  }

  config->voltage_threshold = document["voltage_threshold"];
  config->dmx_address = document["dmx_address"];
  config->dmx_pyro0_auth = document["dmx_pyro0_auth"];
  config->dmx_pyro1_auth = document["dmx_pyro1_auth"];
  config->dmx_pyro0_fire = document["dmx_pyro0_fire"];
  config->dmx_pyro1_fire = document["dmx_pyro1_fire"];

  // print system config to serial
  Serial.print("voltage_threshold: ");
  Serial.println(config->voltage_threshold);
  Serial.print("dmx_address: ");
  Serial.println(config->dmx_address);
  Serial.print("dmx_pyro0_auth: ");
  Serial.println(config->dmx_pyro0_auth);
  Serial.print("dmx_pyro1_auth: ");
  Serial.println(config->dmx_pyro1_auth);
  Serial.print("dmx_pyro0_fire: ");
  Serial.println(config->dmx_pyro0_fire);
  Serial.print("dmx_pyro1_fire: ");
  Serial.println(config->dmx_pyro1_fire);

  Serial.println("Config loaded \n");

  return true;
}

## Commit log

2022-11-19 Close file in correct place
    [Config.ino]
2022-11-19 Fix slow dmx arrival
    [Software.ino]
